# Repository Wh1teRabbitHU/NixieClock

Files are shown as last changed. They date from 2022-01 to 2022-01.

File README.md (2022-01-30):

# NixieClock

It's a custom design nixie clock, with code, schematics and board design.

## Design

### Nixie Clock - Controller

Source: ./design/NixieDisplayControllerV2

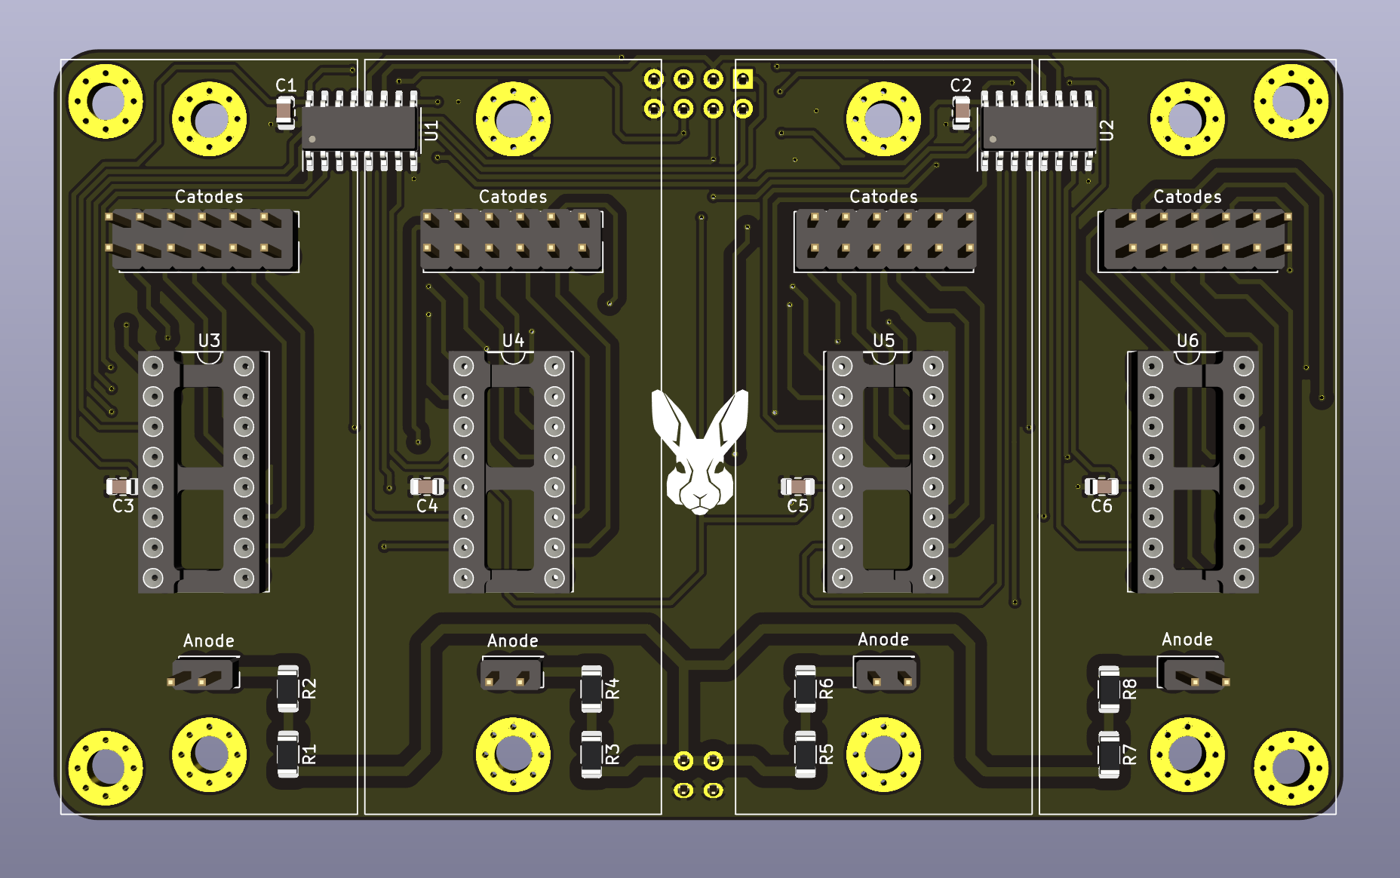
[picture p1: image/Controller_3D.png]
Controller 3D


### Nixie Clock - Mother Board

Source: ./design/NixieDisplayMotherBoardV2

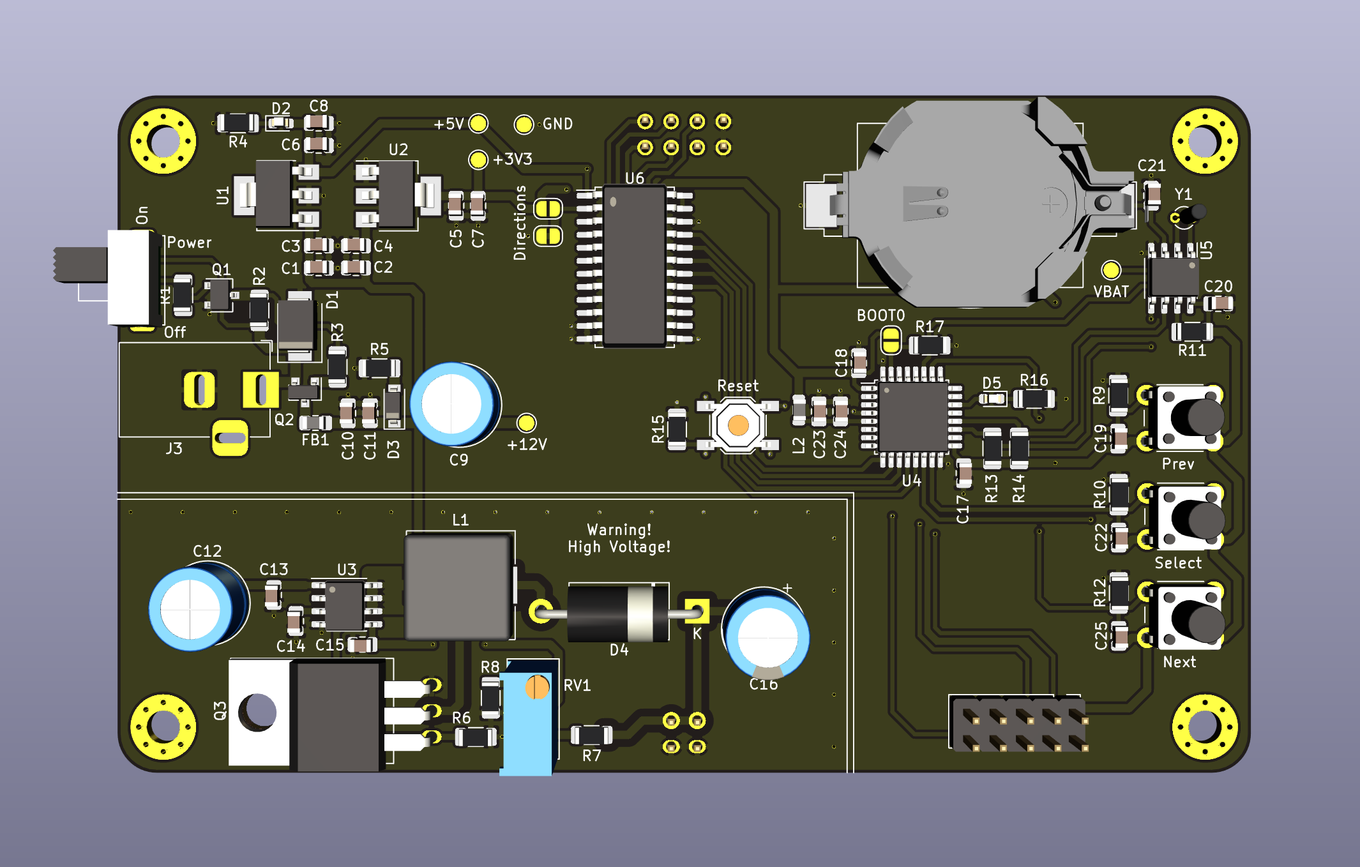
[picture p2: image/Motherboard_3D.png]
Mother Board 3D


## Assembly

Under the folder assembly, you can find the generated files from kicad or if you want to order directly from JLCPB, then the compressed files ending with {Board_Name}_Gerber.zip can be used.

## Code

The mother board is controlled by an STM32L031 MCU and the code is created by using STMCube IDE. To upload the code, you just need to import the project and using an ST Link, you just need to upload directly to the chip. (No USART exposed)

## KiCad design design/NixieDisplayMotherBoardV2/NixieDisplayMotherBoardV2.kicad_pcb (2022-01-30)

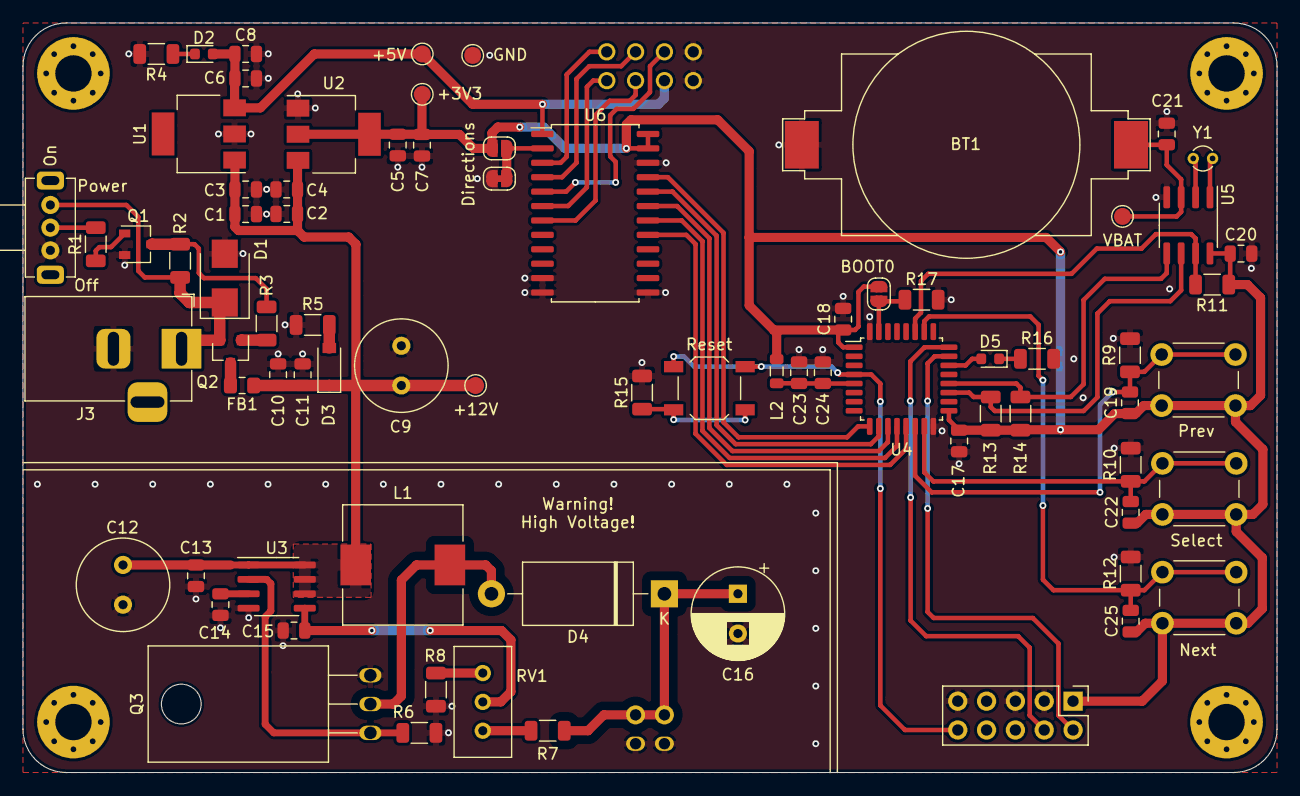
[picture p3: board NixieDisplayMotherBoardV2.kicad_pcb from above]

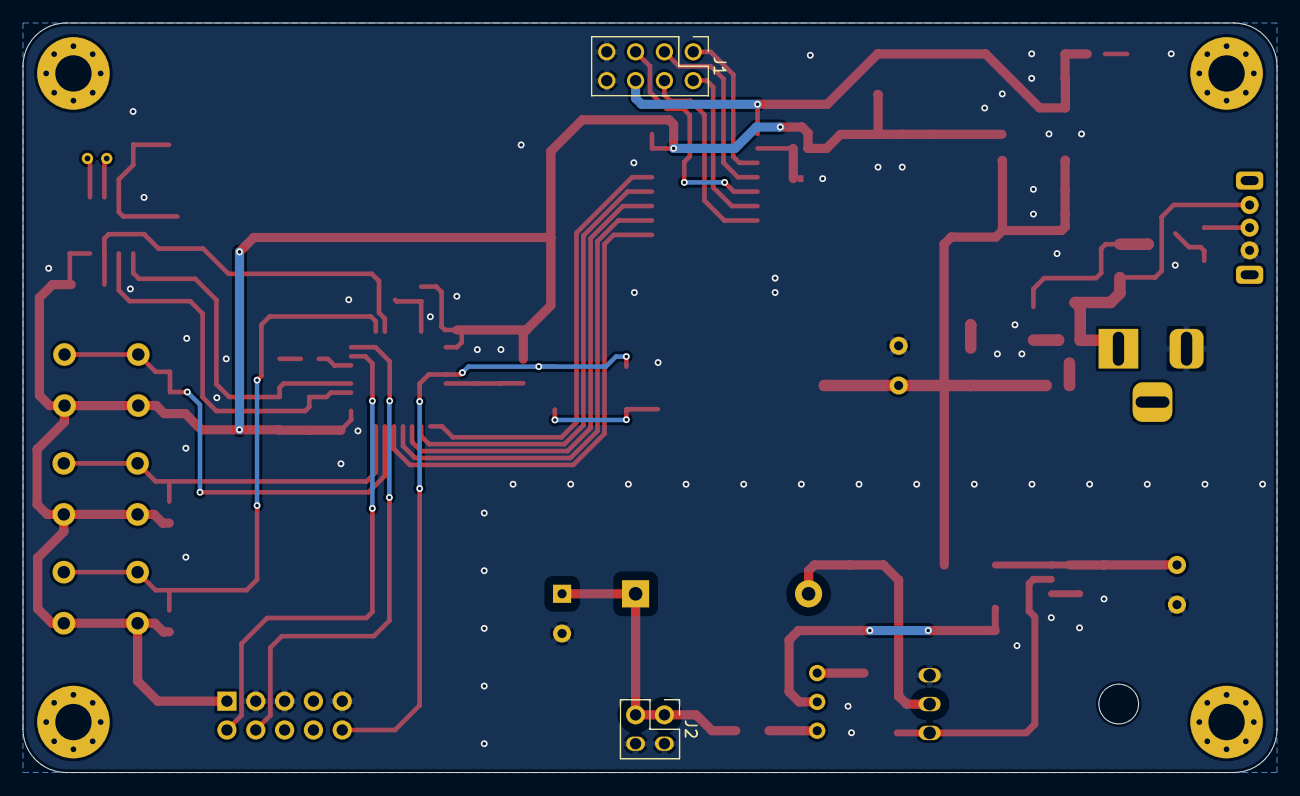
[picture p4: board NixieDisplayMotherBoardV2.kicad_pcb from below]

Board: 2 copper layers, 110.5 x 66.0 mm, 83 parts (2 on the bottom side), 47 nets.

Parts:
BT1: 3V Battery Cell; CR2032-BS-6-1
C1, C2, C23: 1uF; C_0805_2012Metric
C3, C4, C5, C6, C11, C13, C15, C17, C18, C19, C20, C21, C22, C24, C25: 0.1uF; C_0805_2012Metric
C7, C8, C10: 22uF; C_0805_2012Metric
C9, C12: 220uF; C_Radial_D8.0mm_H7.0mm_P3.50mm
C14: 1nF; C_0805_2012Metric
C16: 4.7uF 400V; CP_Radial_D8.0mm_P3.50mm
D1: SMBJ12CA-13-F; D_SMB
D2: Power Indicator; LED_0603_1608Metric
D3: 12V Zener; D_SOD-123
D4: HER504; D_DO-27_P15.24mm_Horizontal
D5: LED; LED_0603_1608Metric
FB1: FB 100; L_0805_2012Metric_Pad1.15x1.40mm_HandSolder
H1, H2, H3, H4: MountingHole; MountingHole_3.2mm_M3_Pad_Via
J1: Data Connector; PinHeader_2x04_P2.54mm_Vertical
J2: High Voltage Connector; PinHeader_2x02_P2.54mm_Vertical
J3: Barrel_Jack; BarrelJack_Horizontal
J4: SWD; PinHeader_2x05_P2.54mm_Vertical
JP1: BOOT0 EN; SolderJumper-2_P1.3mm_Open_RoundedPad1.0x1.5mm
JP2: Direction High; SolderJumper-2_P1.3mm_Open_RoundedPad1.0x1.5mm
JP3: Direction Low; SolderJumper-2_P1.3mm_Bridged_RoundedPad1.0x1.5mm
L1: 470uH 600mA; L_10.4x10.4_H4.8
L2: 39nH; L_0805_2012Metric
Q1: PMBT3904; SOT-23W
Q2: PMV50EPEAR; SOT-23
Q3: IRF840A; TO-220-3_Horizontal_TabDown
R1, R2, R9, R10, R11, R12, R15, R17: 10K; R_1206_3216Metric
R3, R4, R16: 1K; R_1206_3216Metric
R5: 100; R_1206_3216Metric
R6: 330; R_1206_3216Metric
R7: 750k; R_1206_3216Metric
R8: 4.7k; R_1206_3216Metric
R13, R14: 2.2K; R_1206_3216Metric
RV1: 3k; Potentiometer_Bourns_3296W_Vertical
SW1: SW_SPDT; Toggle-Switch-SK12D07VG4
SW2: Prev BTN; SW_PUSH_6mm_H9.5mm
SW3: Select BTN; SW_PUSH_6mm_H9.5mm
SW4: Next BTN; SW_PUSH_6mm_H9.5mm
SW5: Reset BTN; SW_SPST_TL3342
TP1: GND TP; TestPoint_Pad_D1.5mm
TP2: +3V3 TP; TestPoint_Pad_D1.5mm
TP3: +5V TP; TestPoint_Pad_D1.5mm
TP4: +12V TP; TestPoint_Pad_D1.5mm
TP5: VBAT TP; TestPoint_Pad_D1.5mm
U1: LM2940G-50-AA3-R; SOT-223
U2: AMS1117-3.3; SOT-223-3_TabPin2
U3: MC34063AD; SOIC-8_3.9x4.9mm_P1.27mm
U4: STM32L031K6Tx; LQFP-32_7x7mm_P0.8mm
U5: DS1338Z-33+; SOIC-8_3.9x4.9mm_P1.27mm
U6: 74LVC4245A; SOP-24_7.5x15.4mm_P1.27mm
Y1: 32.768KHz; Crystal_Round_D1.5mm_Vertical

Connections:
/+3V3: C5.1, C7.1, C17.1, C18.1, C19.1, C20.1, C22.1, C25.1, J4.1, JP1.2, JP2.1, L2.1, R11.1, R13.1, R14.1, SW2.2, SW3.2, SW4.2, TP2.1, U2.2, U4.1, U4.17, U5.8, U6.23, U6.24
/+5V: C6.1, C8.1, D2.2, J1.6, TP3.1, U1.3, U6.1
/+12V: C1.1, C2.1, C3.1, C4.1, C9.1, C10.1, C11.1, C12.1, C13.1, D3.1, FB1.1, L1.1, TP4.1, U1.1, U2.3, U3.1, U3.6, U3.7, U3.8
/+180V: C16.1, D4.1, J2.1, J2.3, R7.1
/DATA_CLK: J1.3, U6.4
/DATA_IN: J1.1, U6.3
/DATA_LATCH: J1.5, U6.5
/GND: BT1.2, C1.2, C2.2, C3.2, C4.2, C5.2, C6.2, C7.2, C8.2, C9.2, C10.2, C11.2, C12.2, C13.2, C14.2, C15.2, C16.2, C17.2, C18.2, C20.2, C21.2, C23.2, C24.2, D1.2, J1.7, J1.8, J2.2, J2.4, J3.2, J4.3, J4.5, J4.9, JP3.1, Q1.2, Q3.3, R4.2, R5.2, R6.2, R8.2, R9.2, R10.2, R12.2, R15.2, R16.2, R17.2, SW1.3, TP1.1, U1.2, U2.1, U3.4, U4.16, U4.32, U5.4, U6.11, U6.12, U6.13, U6.22
/VBAT: BT1.1, C21.1, TP5.1, U5.3
/uController/+3V3A: C23.1, C24.1, L2.2, U4.5
/uController/BOOT0: JP1.1, R17.1, U4.31
/uController/DATA_CLK_3V3: U4.10, U6.20
/uController/DATA_IN_3V3: U4.9, U6.21
/uController/DATA_LATCH_3V3: U4.11, U6.19
/uController/I2C1_SCL: R13.2, U4.19, U5.6
/uController/I2C1_SDA: R14.2, U4.20, U5.5
/uController/NEXT_BTN: C25.2, R12.1, SW4.1, U4.26
/uController/PREV_BTN: C19.2, R9.1, SW2.1, U4.14
/uController/RESET: J4.10, SW5.1, U4.4
/uController/RTC_INTERRUPT: R11.2, U4.27, U5.7
/uController/SELECT_BTN: C22.2, R10.1, SW3.1, U4.15
/uController/SIGNAL_LED: D5.2, U4.22
/uController/SWCLK: J4.4, U4.24
/uController/SWDIO: J4.2, U4.23
/uController/~DATA_CLR_3V3: U4.13, U6.17
/uController/~OUTPUT_EN_3V3: U4.12, U6.18
/~DATA_CLR: J1.4, U6.7
/~OUTPUT_EN: J1.2, U6.6
unnamed: C14.1, U3.3
unnamed: C15.1, RV1.2, U3.5
unnamed: D1.1, J3.1, Q2.2, R2.1, SW1.1
unnamed: D2.1, R4.1
unnamed: D3.2, R5.1
unnamed: D4.2, L1.2, Q3.2
unnamed: D5.1, R16.1
unnamed: FB1.2, Q2.3
unnamed: JP2.2, JP3.2, U6.2
unnamed: Q1.1, R1.1
unnamed: Q1.3, R2.2, R3.2
unnamed: Q2.1, R3.1
unnamed: Q3.1, R6.1, U3.2
unnamed: R1.2, SW1.2
unnamed: R7.2, RV1.3
unnamed: R8.1, RV1.1
unnamed: R15.1, SW5.2
unnamed: U5.1, Y1.2
unnamed: U5.2, Y1.1

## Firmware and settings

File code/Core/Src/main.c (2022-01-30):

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
/* Includes ------------------------------------------------------------------*/
#include "main.h"

/* USER CODE BEGIN Includes */
#include "display.h"
#include "ds1338z.h"
/* USER CODE END Includes */

I2C_HandleTypeDef hi2c1;

void SystemClock_Config(void);
static void MX_GPIO_Init(void);
static void MX_I2C1_Init(void);
/**
  * @brief  The application entry point.
  * @retval int
  */
int main(void)
{
  /* MCU Configuration--------------------------------------------------------*/

  /* Reset of all peripherals, Initializes the Flash interface and the Systick. */
  HAL_Init();

  /* Configure the system clock */
  SystemClock_Config();

  /* Initialize all configured peripherals */
  MX_GPIO_Init();
  MX_I2C1_Init();
  /* USER CODE BEGIN 2 */
  display_init();
  /* USER CODE END 2 */

  /* Infinite loop */
  /* USER CODE BEGIN WHILE */

  DS1338Z_time time = {0};

  DS1338Z_readTime(&hi2c1, &time);

  time.mode = H24;

  DS1338Z_writeTime(&hi2c1, &time);

  uint32_t tick = 0;
  uint8_t lockButton = 0;
  uint8_t selectMode = 0;

  while (1) {
    /* USER CODE END WHILE */

    /* USER CODE BEGIN 3 */

	if (tick % 200 == 0) {
		DS1338Z_readTime(&hi2c1, &time);
		display_showTime(time.hour, time.minute);
	}

	if (!lockButton) {
		uint8_t flip;

		if (HAL_GPIO_ReadPin(PREV_BTN_GPIO_Port, PREV_BTN_Pin)) {
			if (selectMode) {
				time.hour = time.hour == 0 ? 23 : (time.hour - 1);
			} else {
				flip = time.minute == 0;

				if (flip) {
					time.minute = 59;
					time.hour = time.hour == 0 ? 23 : (time.hour - 1);
				} else {
					time.minute = time.minute - 1;
				}
			}

			time.second = 0;

			lockButton = 1;
			DS1338Z_writeTime(&hi2c1, &time);
		} else if (HAL_GPIO_ReadPin(SELECT_BTN_GPIO_Port, SELECT_BTN_Pin)) {
			selectMode = selectMode == 1 ? 0 : 1;
			lockButton = 1;
		} else if (HAL_GPIO_ReadPin(NEXT_BTN_GPIO_Port, NEXT_BTN_Pin)) {
			if (selectMode) {
				time.hour = time.hour == 23 ? 0 : (time.hour + 1);
			} else {
				flip = time.minute == 59;

				if (flip) {
					time.minute = 0;
					time.hour = time.hour == 23 ? 0 : (time.hour + 1);
				} else {
					time.minute = time.minute + 1;
				}
			}

			time.second = 0;

			lockButton = 1;
			DS1338Z_writeTime(&hi2c1, &time);
		}
	} else if (tick % 300 == 0) {
		lockButton = 0;
	}

	HAL_Delay(1);
	tick++;
  }
  /* USER CODE END 3 */
}

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


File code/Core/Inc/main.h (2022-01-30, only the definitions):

#define CTRL_DATA_IN_Pin GPIO_PIN_3
#define CTRL_DATA_IN_GPIO_Port GPIOA
#define CTRL_DATA_CLK_Pin GPIO_PIN_4
#define CTRL_DATA_CLK_GPIO_Port GPIOA
#define CTRL_DATA_LATCH_Pin GPIO_PIN_5
#define CTRL_DATA_LATCH_GPIO_Port GPIOA
#define CTRL_OUT_EN_Pin GPIO_PIN_6
#define CTRL_OUT_EN_GPIO_Port GPIOA
#define CTRL_DATA_CLR_Pin GPIO_PIN_7
#define CTRL_DATA_CLR_GPIO_Port GPIOA
#define PREV_BTN_Pin GPIO_PIN_0
#define PREV_BTN_GPIO_Port GPIOB
#define PREV_BTN_EXTI_IRQn EXTI0_1_IRQn
#define SELECT_BTN_Pin GPIO_PIN_1
#define SELECT_BTN_GPIO_Port GPIOB
#define SELECT_BTN_EXTI_IRQn EXTI0_1_IRQn
#define SIGNAL_LED_Pin GPIO_PIN_12
#define SIGNAL_LED_GPIO_Port GPIOA
#define NEXT_BTN_Pin GPIO_PIN_3
#define NEXT_BTN_GPIO_Port GPIOB
#define NEXT_BTN_EXTI_IRQn EXTI2_3_IRQn
#define RTC_INTERRUPT_Pin GPIO_PIN_4
#define RTC_INTERRUPT_GPIO_Port GPIOB

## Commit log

2022-01-30 Adding design files
    [Display.sch, HighPower.sch, HighVoltagePower.sch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]
2022-01-30 Adding assembly files
    [NixieDisplayControllerV2-B_Cu.gbl, NixieDisplayControllerV2-B_Mask.gbs, NixieDisplayControllerV2-B_Paste.gbp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]
2022-01-30 Creating a driver to the DS1338Z RTC module
2022-01-30 Fixing I2C connection on the design
    [NixieDisplayMotherBoardV2-B_Cu.gbl, NixieDisplayMotherBoardV2-B_Mask.gbs, NixieDisplayMotherBoardV2-B_Paste.gbp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]

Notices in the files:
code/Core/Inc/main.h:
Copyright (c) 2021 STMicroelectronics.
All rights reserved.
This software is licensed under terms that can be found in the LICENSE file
